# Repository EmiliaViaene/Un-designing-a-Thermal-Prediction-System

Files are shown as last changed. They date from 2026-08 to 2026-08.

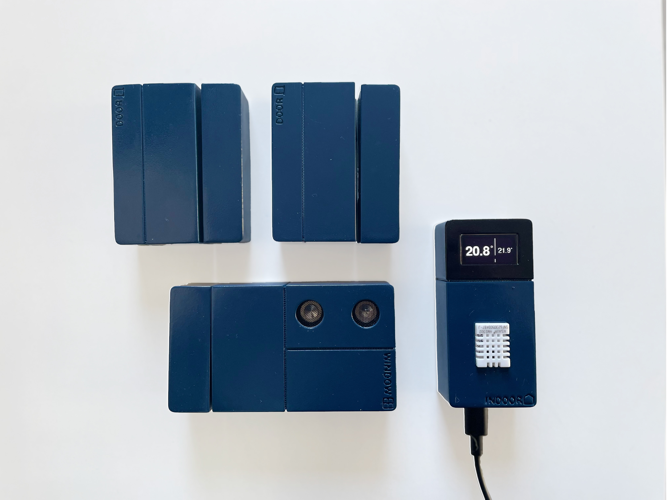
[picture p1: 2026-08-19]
documentation/images/IMG_2418_whiteBG.jpg

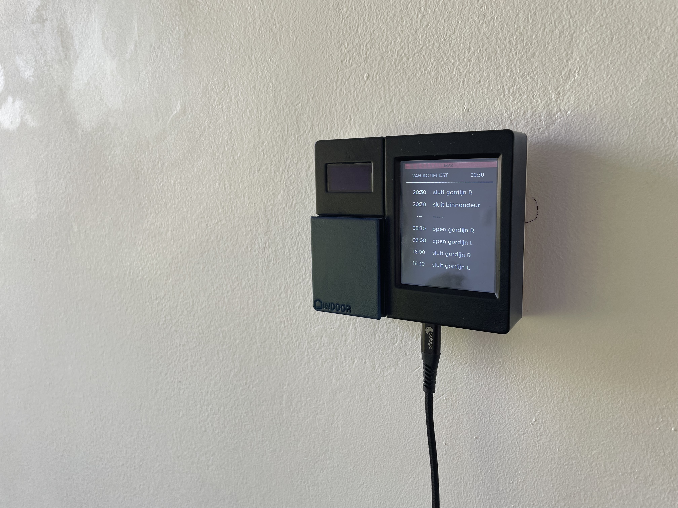
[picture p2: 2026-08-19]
documentation/images/IMG_2538.jpg

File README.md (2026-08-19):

# (Un)designing a Thermal Prediction System
This repository contains the working code, data, 3d-print files, and documentation for a thermal prediction system consisting of four types of sensor devices and an interface. The purpose of this system was to make predictions for changes in the indoor temperature based on weather forecasts and patterns in the thermodynamics of a specific space. These predictions served to anticipate the thermal effects of various shading and ventilating actions. This project is part of a Research through Design study presented in Chapter 6 of the PhD thesis titled: "(Un)designing Learning Agents in Messy Domestic Contexts" by Emilia Viaene (Eindhoven University of Technology, 2026).

# About the Study
This repository accompanies a Research-through-Design  study that explored the role a thermal prediction system (based on thermodynamic sensor data and weather data) could play in supporting household shading and ventilating strategies for thermal comfort. 

The study addressed two research questions:
1. What aspects of household shading and ventilating strategies can or cannot be modeled and predicted by a thermal prediction system based on sensor and weather data?
2. In what ways can suggestions for shading and ventilating actions based on thermal predictions inferred from sensor and weather data be misaligned with situated circumstances?

Four households (H1–H4 in this repository, matching Table 6.1 in the thesis; H4 is the researcher's own household) had a custom sensor kit installed in their living space for several weeks in August–October 2024. The sensor kit logged indoor/outdoor temperature, incoming sunlight through the windows, and window/curtain/door states, supplemented with weather API data. This data was used to iteratively design and deploy a thermal prediction algorithm and an interface that visualized sensor data and, in a later version, simulated thermal effects and suggested shading/ventilating actions.

# Sensor Kit
The sensor kit was designed and developed specifically for the purpose of this study. The complete kit consisted of four sensor devices (described below), equipped with an ESP32-microcontroller. The sensor devices collected thermodynamic variables (temperatures and sunlight) and shading and ventilation states (windows, curtains, doors, and shading). Sensor data was supplemented with API data from local weather stations (outdoor temperature and solar radiation). Data was collected using [DataFoundry](https://data-foundry.net), a research data infrastructure for designers; weather data was collected via the APIs from [OpenWeatherMap](https://openweathermap.org/) and [Meteoserver](https://meteoserver.nl/).

### Windows
The window sensor devices combined an ultrasonic distance sensor to track when curtains were open or closed with an LDR sensor to register changes in incoming light through the window. These devices were installed on each window in the space and logged sensor states at a frequency of sixty seconds When windows stretched over an entire façade, window sensor devices were installed at opposite sides of the window. The purpose of these sensor devices was to capture data about when and how the room was shaded from the sun. Light sensor data was complemented with global solar radiance API data to account for local obstructions in front of the sensor that obstruct the sunlight from hitting a specific (area of a) window.

### Doors
The door sensor devices, equipped with reed sensors to detect when windows or doors were opened or closed. These sensors were installed on windows and outdoor and indoor doors that lead into the space. They logged the reed sensor state with a frequency of sixty seconds. These devices provided data about when the room was exposed to airflow from outside.

### Indoor Temperature
The indoor temperature device included a DHT22 temperature sensor (±0.5°C accuracy) and logged indoor temperature at a frequency of sixty seconds. A small SSD1306 OLED display showed the current indoor and outdoor temperature. While the DHT22 sensor is also capable of collecting humidity data, and while this data is also relevant for the air quality and sensed temperature on the skin, this data was not used in the current study. The indoor temperature data served to provide insight into temperature changes as a result from shading and ventilating actions (i.e., changes in window and door sensor states).  

### Outdoor temperature
The outdoor temperature devices were equipped with waterproof DS18B20 temperature sensors (±0.5°C accuracy). These sensors were placed outside the home of the participants in a shaded area and logged outdoor temperature with a frequency of sixty minutes. This outdoor temperature data served to provide insight into the effect on indoor temperatures in relation to window and door sensor states. This sensor data was complemented with API outdoor temperature data to account for peaks in the data due to e.g. direct sunlight on the sensor.

### Weather data from external APIs
Temperature measurements from nearby weather-stations were accessed from an API called OpenWeatherMap. Global solar radiance measurements were accessed from an API called Meteoserver. Both API data streams were logged at hourly intervals. For the purpose of generating thermal predictions, APIs from the same platforms were used to access forecast data about outdoor temperatures and global solar radiance.

# Thermal Prediction Algorithm
The objective for designing the thermal prediction algorithm was to generate thermal predictions for the next 24 hours and corresponding action lists for shading and ventilating. The resulting algorithm would use weather forecast data to predict fluctuations in indoor temperature under different configurations of window, door, curtain, and shading states. The development of this algorithm was explored using Python Notebooks. The final deployment was based on simulated predictions following the algorithmic logic of the final version of the experimental algorithm. 

### Solar Radiance Model
Because obstructions (e.g., overhangs, trees) are window-specific, the algorithm needed to align global solar radiation measurements with the locally measured light values for each window. This was to ensure that thermal predictions based on solar radiance forecasts were in line with future window-specific light values. The feature set used for this model includes solar radiance values and timestamps (day, time) as input variables and window-specific light sensor values as output variable

### Thermal Prediction Model
Next, the resulting window-specific light value predictions based on solar radiance forecasts in combination with outdoor temperature forecast data served to predict indoor temperature fluctuations based on simulated future window and door sensor states. The feature set used for this model includes outdoor temperature, predicted light values (output from previous model), and pre-set window and door sensor values as input variables and indoor temperatures as output variables. 

### Action List Generation
Finally, the algorithm needed to predict the maximum and minimum temperatures for the next 24 hours and a list of corresponding window and door sensor states.  To do so, the thermal prediction model would run through all possible sensor states for each of the next 24 hours to output the sensor states that correspond with either the max or the min setting.

# Interface
The interface used a TFT LCD touchscreen with an included ESP32 development board (ESP32-2432S028R, commonly referred to as Cheap Yellow Display or CYD). The display was programmed using Arduino, and the graphical user interface was designed using SquareLine Studio. Through the interface, household-specific data from the datasets on the DataFoundry database could be retrieved and manipulated. Two iterations of the interface were deployed consecutively. In the first version, participants could consult historical sensor- and weather data visualizations. The second version enabled participants to configure future window and sensor states and consult corresponding thermal predictions and shading and ventilating action lists.

# Data Infrastructure
The sensor devices were equipped with ESP32 microcontrollers with Wi-Fi capabilities that allowed them to send data from the sensors to a secure database on DataFoundry. Data from each sensor device and from the API’s was collected in five separate datasets on the DataFoundry platform. These datasets were accessed for data processing to produce new (dynamic) datasets to be accessed by the interface.
All sensor devices except the indoor temperature device were powered by lithium-ion batteries. To notify users when the batteries were drained and required recharging (with the supplied portable power bank), a script running on the DataFoundry platform detected when sensor data logging had stopped and then sent notifications to participants through a Telegram bot. 
Two Python scripts served to make the collected data and the output of the thermal prediction algorithm accessible from the interface. The first script merged hourly data from the separate datasets for each participant from the last three days and sent it to a dynamic dataset on DataFoundry. This dataset could be accessed by the interface to display the (household-specific) sensor and weather data history. The second script accessed weather forecast API data (temperature and solar radiance) and ran the thermal prediction algorithm to generate thermal predictions and action lists, to produce dynamic thermal prediction datasets per household. These dynamic datasets can be accessed by the interface to display the thermal predictions and action lists and manipulated by changing thermal prediction settings (i.e., determining future window/door sensor states). Note that this second script was run only once to deploy the simulated thermal predictions for H2.

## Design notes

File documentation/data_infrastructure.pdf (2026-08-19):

## 1. Data collection (sensors)

This document explains the technical details for the Cool AI study setup; how data is sent from and to DataFoundry, to Python notebooks and scripts, and to the interface. On page 1 I explain the data collection part of the project, on page 2 the data processing part, and on page 3 you will fi nd the full diagram (data collection + data processing).

Data is collected at the participants’ home by four kinds of sensor devices: (1) window (reed sensor, light sensor, ultrasonic sensor); (2) door (reed sensor); (3) indoor temperature (DHT22), and (4) outdoor temperature (DS18B20).

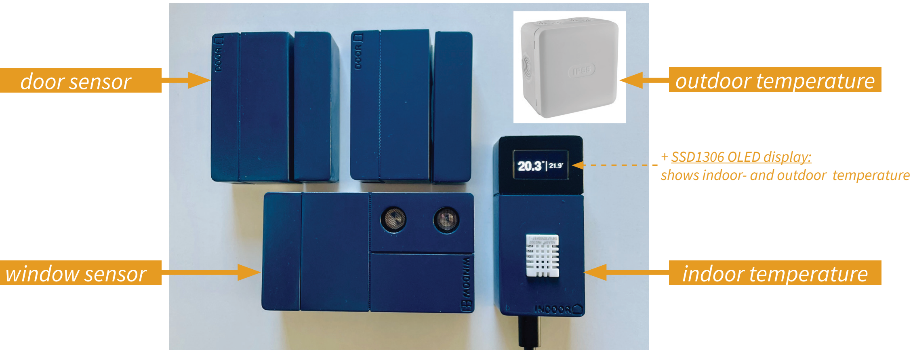
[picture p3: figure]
door sensor; outdoor temperature; window sensor; indoor temperature; + SSD1306 OLED display: shows indoor- and outdoor temperature

These devices are all controlled by an esp32 microcontroller and send data via OOCSI to their resp. IoT databases in DataFoundry. An entity dataset also logs the last timestamps for incoming data from each sensor to monitor whether the battery is still live (& send a Telegram message to the participant to charge the battery in case of dead battery).

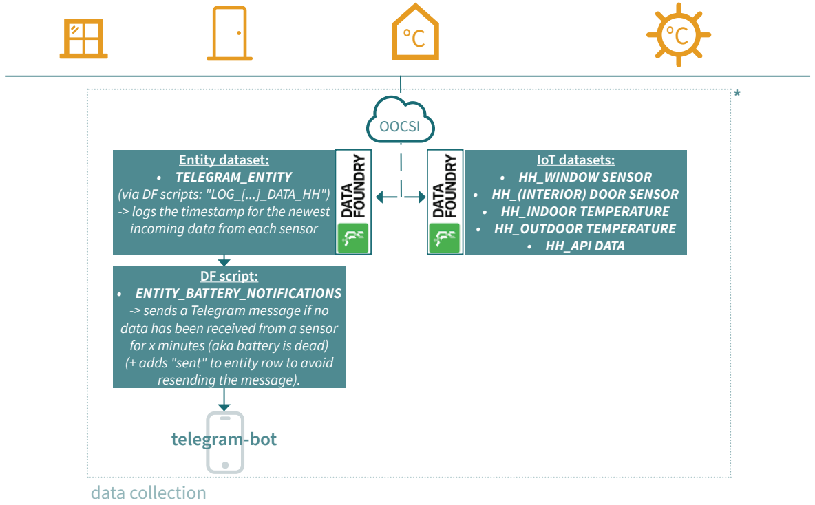
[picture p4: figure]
IoT datasets: • HH_WINDOW SENSOR • HH_(INTERIOR) DOOR SENSOR • HH_INDOOR TEMPERATURE • HH_OUTDOOR TEMPERATURE • HH_API DATA; Entity dataset: • TELEGRAM_ENTITY (via DF scripts: "LOG_[...]_DATA_HH") -> logs the timestamp for the newest incoming data from each sensor; DF script: • ENTITY_BATTERY_NOTIFICATIONS -> sends a Telegram message if no data has been received from a sensor for x minutes (aka battery is dead) (+ adds "sent" to entity row to avoid resending the message).; OOCSI; data collection; telegram-bot

* (The DataFoundry project also contains “PILOT” versions of each dataset and script for testing purposes)

# COOL AI: technical details

## window state door state indoor temperature outdoor temperature

DHT22 sensor (temperature)

DS18B20 sensor (temperature)
OpenWeather api (temperature, description)

reed sensor
ldr sensor
ultrasonic distance sensor reed sensor

## 2. Data processing (to interface)

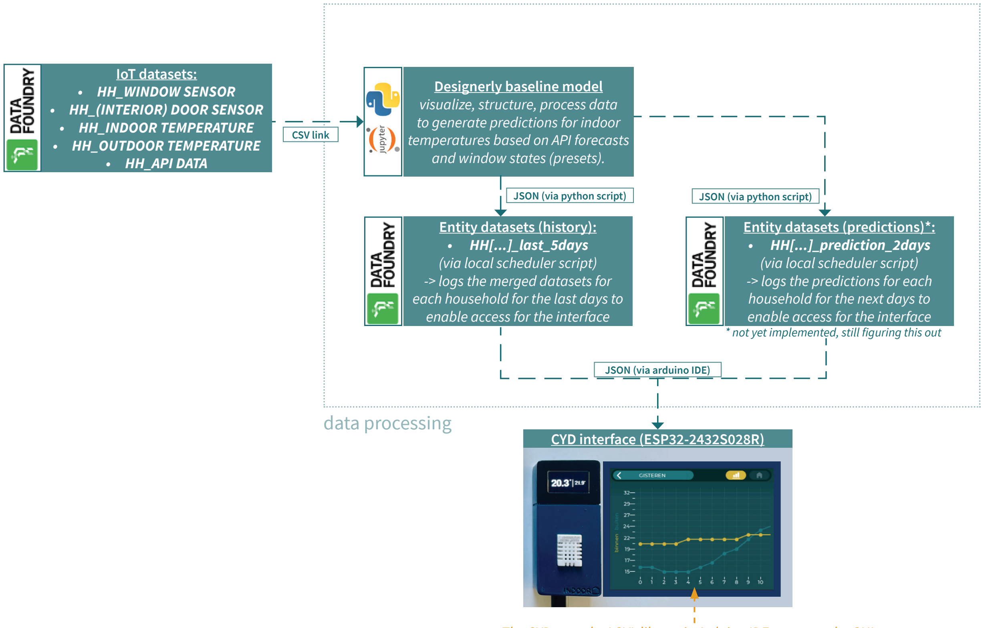
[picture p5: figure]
Designerly baseline model visualize, structure, process data to generate predictions for indoor temperatures based on API forecasts and window states (presets).; Entity datasets (history): • HH[...]_last_5days (via local scheduler script) -> logs the merged datasets for each household for the last days to enable access for the interface; Entity datasets (predictions)*: • HH[...]_prediction_2days (via local scheduler script) -> logs the predictions for each household for the next days to enable access for the interface; CYD interface (ESP32-2432S028R); JSON (via python script); JSON (via arduino IDE); data processing; CSV link; IoT datasets: • HH_WINDOW SENSOR • HH_(INTERIOR) DOOR SENSOR • HH_INDOOR TEMPERATURE • HH_OUTDOOR TEMPERATURE • HH_API DATA

* not yet implemented, still figuring this out

Data from the IoT datasets is accessed via their CSV links in Python Notebooks to visualize, structure, and process the data to create a ‘Designerly Baseline Model’ that generates predictions for indoor temperatures based on forecast (API) data and (preset) window states.

The output from the resulting Python scripts is sent back into (Entity) datasets in DataFoundry, so that the data can be accessed as a JSON by the CYD interface (ESP32-2432S028R). The Python scripts are run at fixed time intervals by a scheduler (local).

The interface has two tabs: “history” and “predictions”:
1. History tab: A python script merges the datasets and sends the last 5 days of relevant data back to an Entity dataset in DataFoundry for each participant. This entity dataset can then be accessed (as a JSON) by the CYD to display this data in the history tab.
2. Predictions tab*: A python script processes the datasets and generates indoor temperature predictions for each window/ curtain/shading state based on API forecast data. This results in multiple datasets (per window/curtain/shading state). These datasets are sent back to (Entity) datasets in DataFoundry so they can be accessed (as JSON) by the CYD to display the predictions and change them according to user input (changing the window/curtain/shading states).
* This part has not been implemented yet, and I am still figuring out how exactly to do this (unsure if this approach will be the final approach).

The CYD uses the LGVL library in Arduino IDE to create the GUI. (+ I use SquareLine to design the GUI)

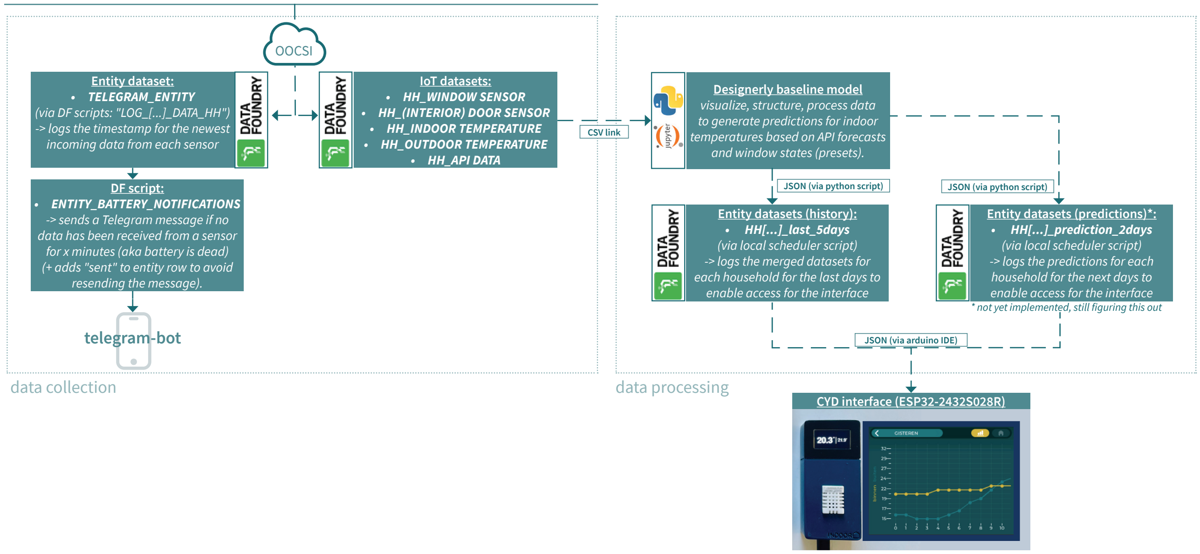
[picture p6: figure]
IoT datasets: • HH_WINDOW SENSOR • HH_(INTERIOR) DOOR SENSOR • HH_INDOOR TEMPERATURE • HH_OUTDOOR TEMPERATURE • HH_API DATA; Designerly baseline model visualize, structure, process data to generate predictions for indoor temperatures based on API forecasts and window states (presets).; Entity dataset: • TELEGRAM_ENTITY (via DF scripts: "LOG_[...]_DATA_HH") -> logs the timestamp for the newest incoming data from each sensor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

* not yet implemented, still fi guring this out

## 3. Full diagram

window state door state | indoor temperature | outdoor temperature
| °C | °C

DHT22 sensor (temperature)

DS18B20 sensor (temperature) OpenWeather api (temperature, description)

reed sensor
ldr sensor
ultrasonic distance sensor reed sensor

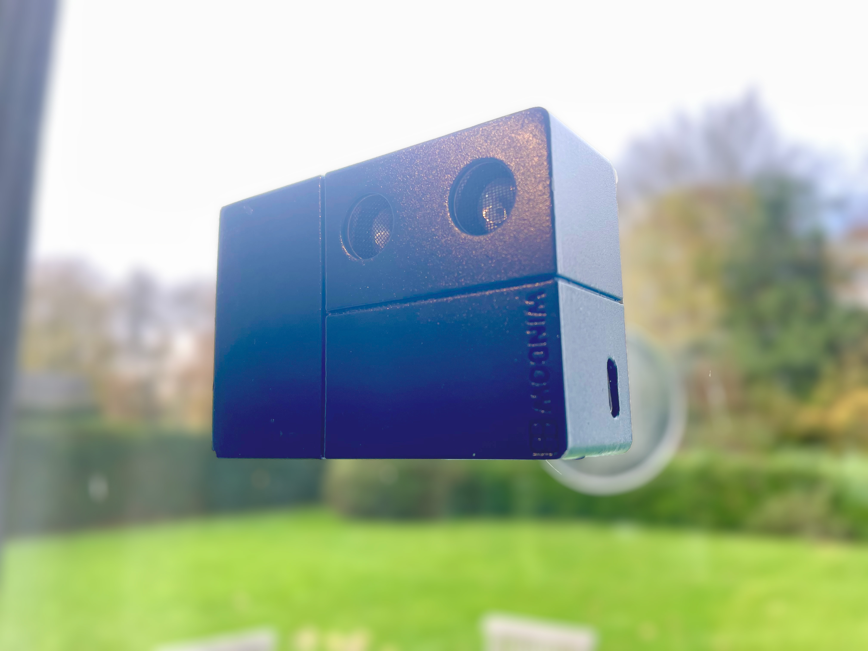
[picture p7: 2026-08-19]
documentation/images/IMG_3446_brighter_blur.jpg

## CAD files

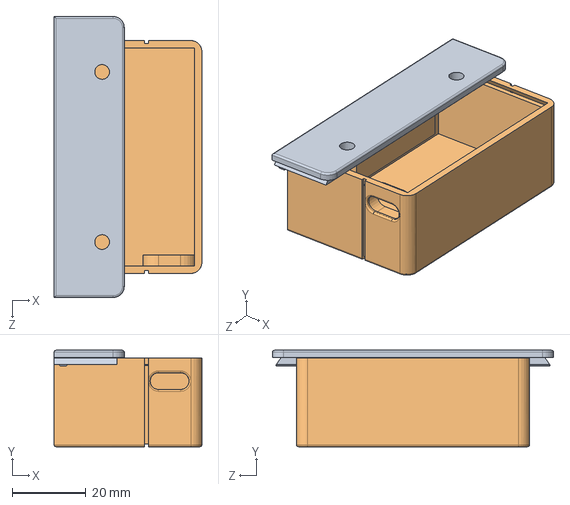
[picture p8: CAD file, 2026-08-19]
hardware/3D_print_files/door-sensor/reed (magnet) box/MAGNET__DOORbox.SLDASM
40.0 x 26.1 x 76.0 mm
MAGNET_DOORbox_V2
MAGNET_DOOR_lid_V2

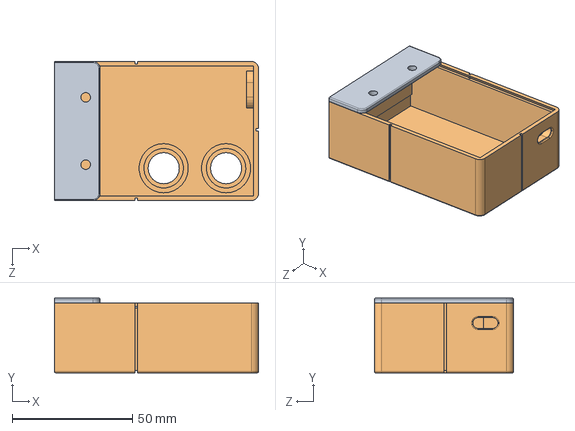
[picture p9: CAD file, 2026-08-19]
hardware/3D_print_files/window-sensor/reed (magnet) box/MAGNET_windowbox.SLDASM
85.0 x 31.1 x 58.0 mm
MAGNET_windowbox_V2
MAGNET_sliding-lid_V2

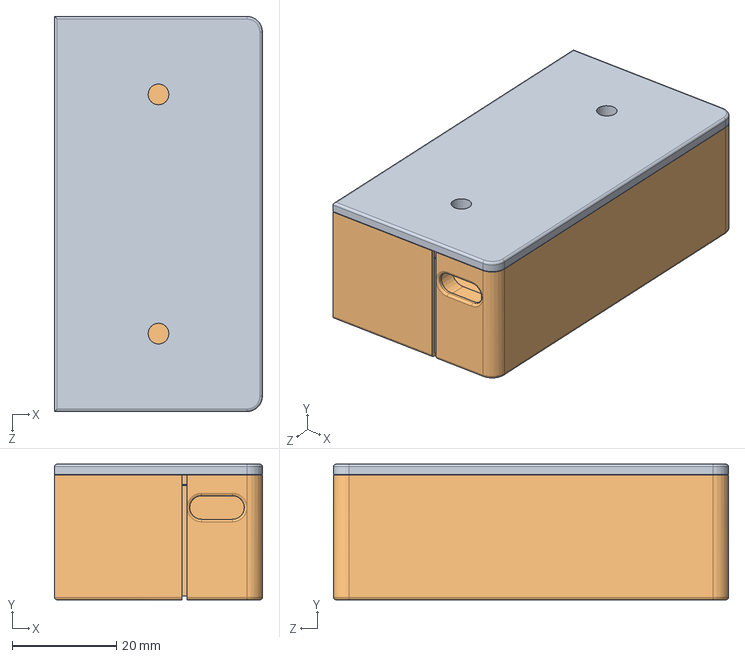
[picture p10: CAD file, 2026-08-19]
hardware/3D_print_files/door-sensor/DOORbox.SLDASM
40.0 x 26.1 x 76.0 mm
DOORwindowbox_V2
DOOR_lid_V2

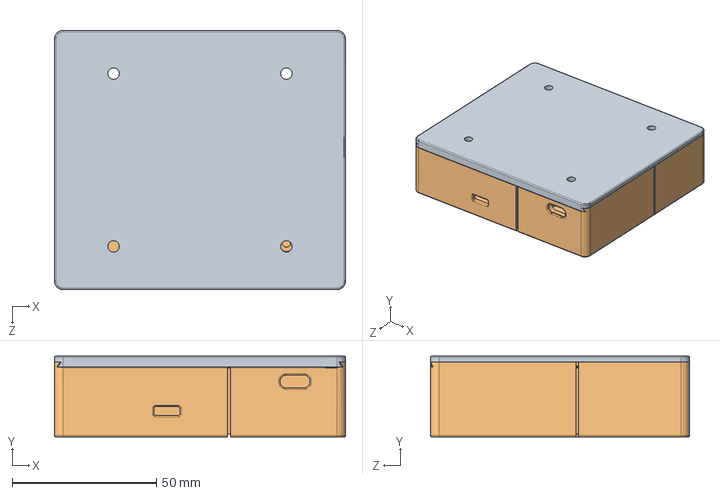
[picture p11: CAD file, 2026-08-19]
hardware/3D_print_files/CYD interface/CYD_combined.SLDASM
101.0 x 28.1 x 90.0 mm
CYD_combined_box
CYD_combined_lid

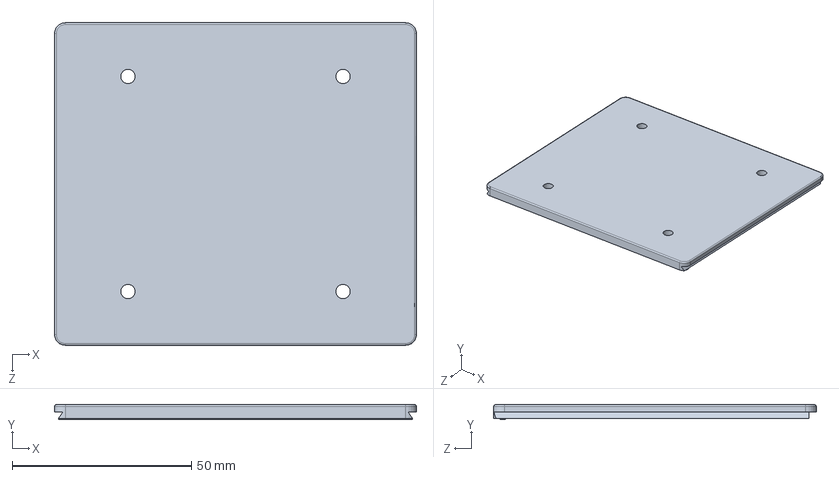
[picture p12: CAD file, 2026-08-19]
hardware/3D_print_files/CYD interface/CYD_combined_lid.SLDPRT
101.0 x 4.10 x 90.0 mm

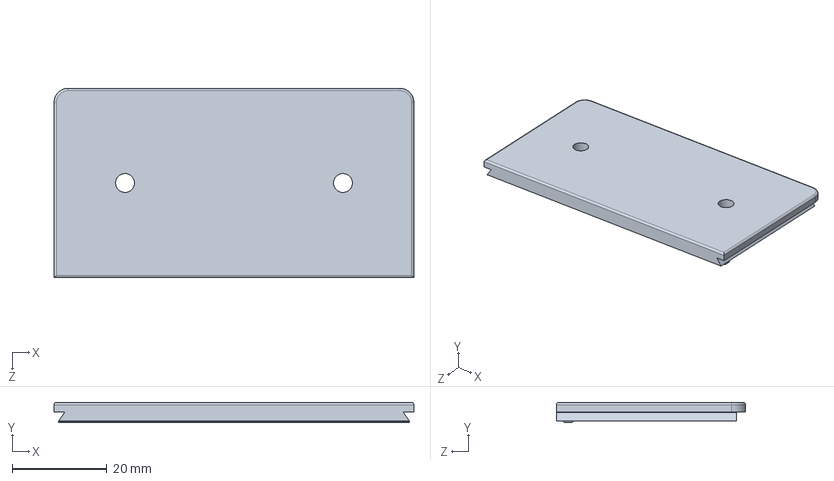
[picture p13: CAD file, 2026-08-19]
hardware/3D_print_files/door-sensor/DOOR_lid_V2.SLDPRT
76.0 x 4.25 x 40.0 mm

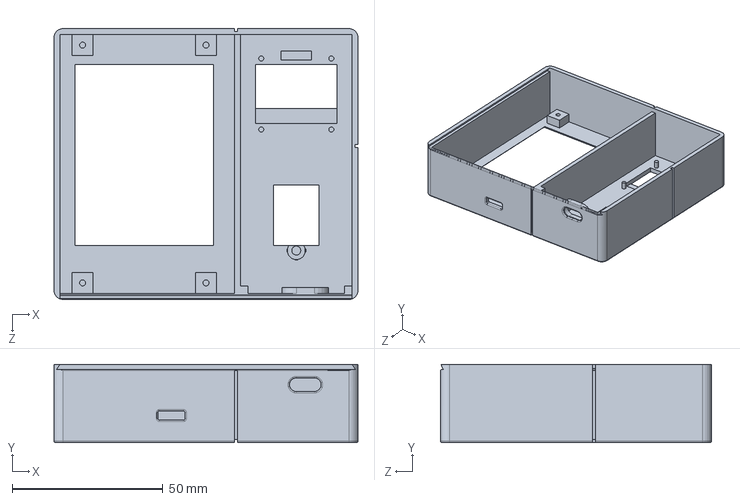
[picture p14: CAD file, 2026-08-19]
hardware/3D_print_files/CYD interface/CYD_combined_box.SLDPRT
101.0 x 26.0 x 90.0 mm

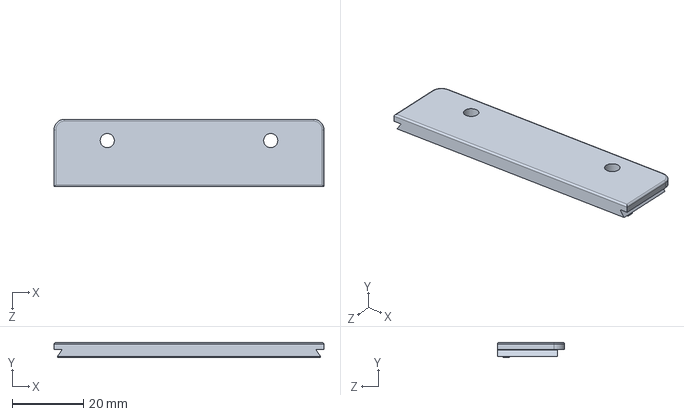
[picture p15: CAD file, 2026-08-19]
hardware/3D_print_files/door-sensor/reed (magnet) box/MAGNET_DOOR_lid_V2.SLDPRT
76.0 x 4.25 x 19.0 mm

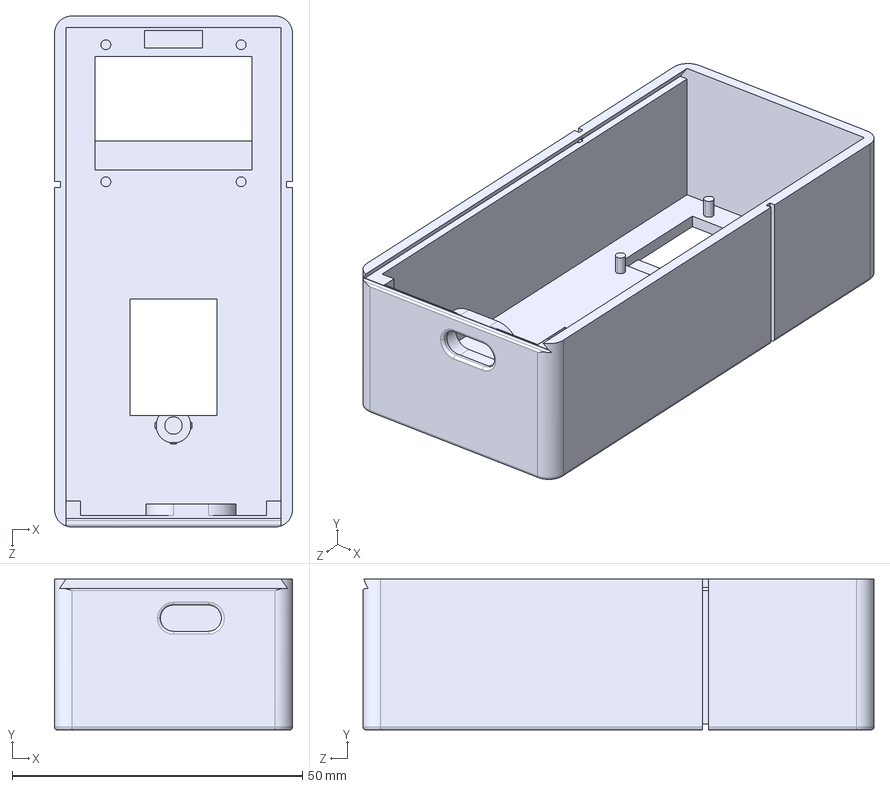
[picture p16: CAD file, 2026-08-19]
hardware/3D_print_files/Indoor/Indoor_box.STEP
41.0 x 26.0 x 88.0 mm

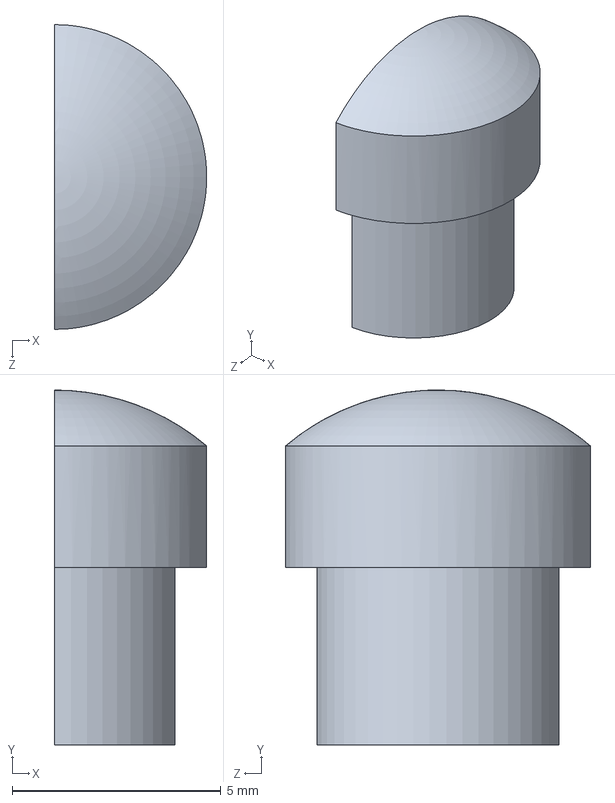
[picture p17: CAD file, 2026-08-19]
hardware/3D_print_files/window-sensor/light sensor dome.SLDPRT
3.65 x 8.50 x 7.30 mm

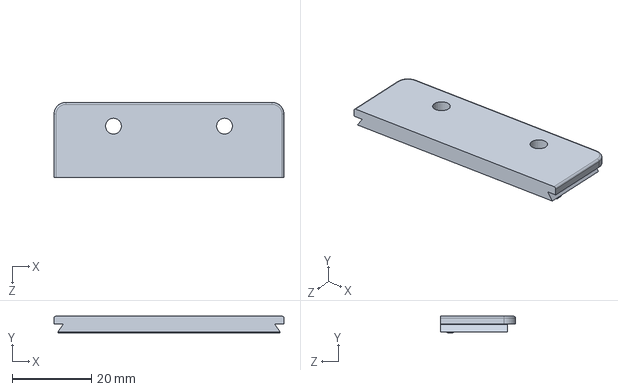
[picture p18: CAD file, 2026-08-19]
hardware/3D_print_files/window-sensor/reed (magnet) box/MAGNET_sliding-lid_V2.SLDPRT
58.0 x 4.20 x 19.0 mm

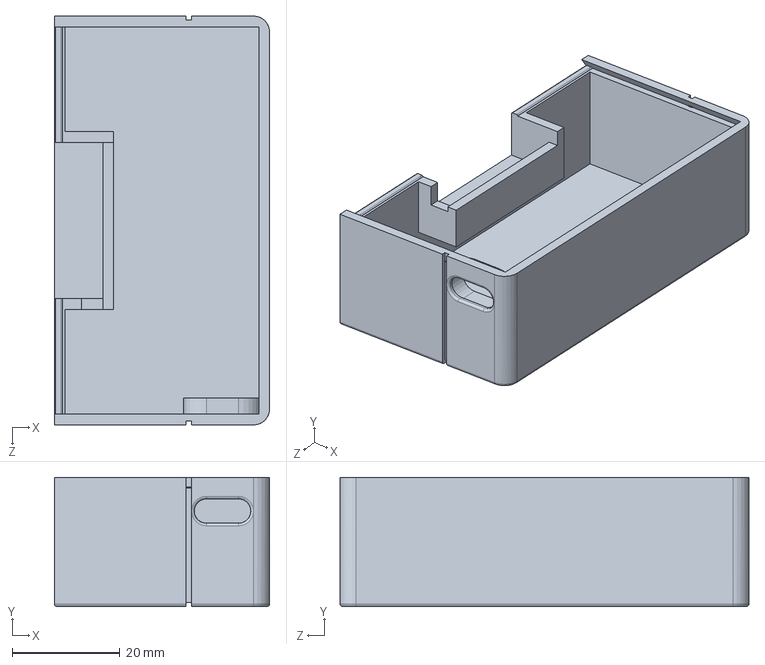
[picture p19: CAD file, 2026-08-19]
hardware/3D_print_files/door-sensor/DOORwindowbox_V2.SLDPRT
40.0 x 24.0 x 76.0 mm

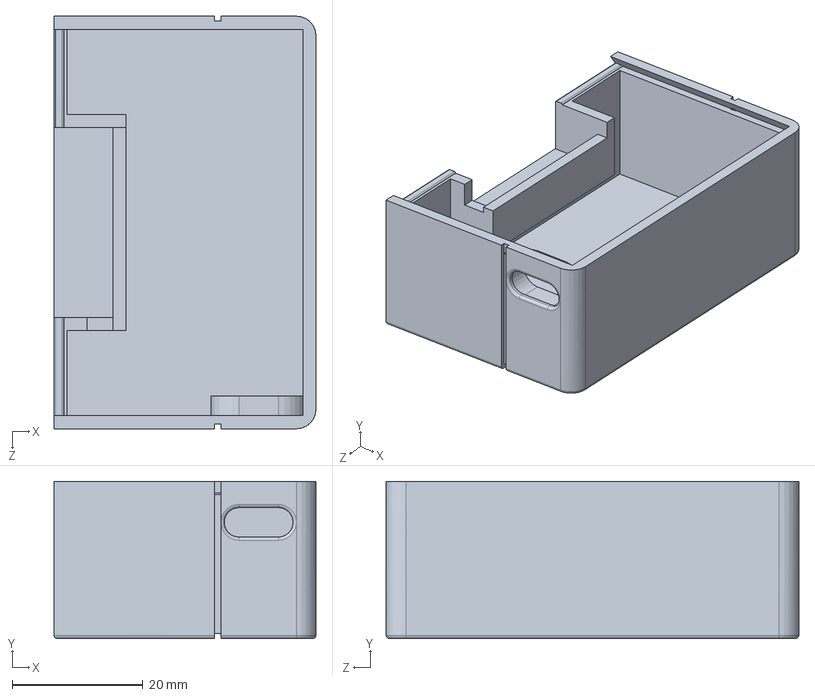
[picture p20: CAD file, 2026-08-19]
hardware/3D_print_files/door-sensor/reed (magnet) box/MAGNET_DOORbox_V2.SLDPRT
40.0 x 24.0 x 63.0 mm

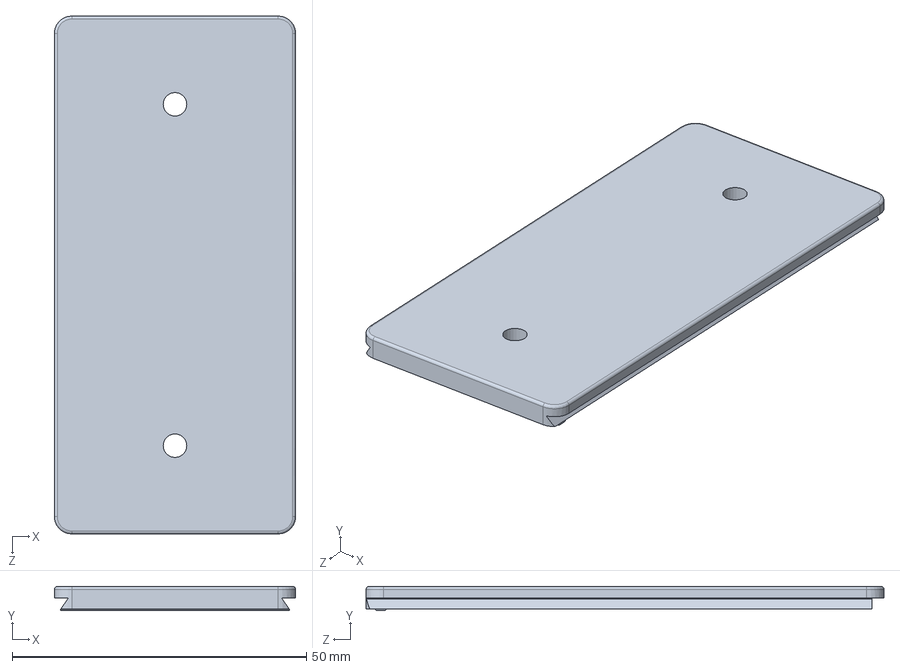
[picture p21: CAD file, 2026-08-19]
hardware/3D_print_files/Indoor/Indoor_lid.SLDPRT
41.0 x 4.10 x 88.0 mm

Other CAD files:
hardware/3D_print_files/Indoor/Indoor.SLDASM
hardware/3D_print_files/window-sensor/windowbox.SLDASM
hardware/3D_print_files/CYD interface/CYD_combined_dekplaatje.SLDPRT
hardware/3D_print_files/window-sensor/reed (magnet) box/MAGNET_windowbox_V2.SLDPRT
hardware/3D_print_files/CYD interface/CYD_combined_box.STL
hardware/3D_print_files/CYD interface/CYD_combined_dekplaatje.STL
hardware/3D_print_files/CYD interface/CYD_combined_lid.STL
hardware/3D_print_files/CYD interface/cyd_box.SLDPRT
hardware/3D_print_files/Indoor/Indoor_box.SLDPRT
hardware/3D_print_files/Indoor/Indoor_lid.STL
hardware/3D_print_files/door-sensor/DOOR_lid_V2.STL
hardware/3D_print_files/door-sensor/DOORwindowbox_V2.STL
hardware/3D_print_files/door-sensor/reed (magnet) box/MAGNET_DOOR_lid_V2.STL
hardware/3D_print_files/door-sensor/reed (magnet) box/MAGNET_DOORbox_V2.STL
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

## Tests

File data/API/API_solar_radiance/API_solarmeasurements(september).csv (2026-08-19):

straling | ts
0 | 2024-09-01 00:00:00
0 | 2024-09-01 01:00:00
0 | 2024-09-01 02:00:00
0 | 2024-09-01 03:00:00
0 | 2024-09-01 04:00:00
15 | 2024-09-01 05:00:00
55 | 2024-09-01 06:00:00
71 | 2024-09-01 07:00:00
160 | 2024-09-01 08:00:00
217 | 2024-09-01 09:00:00
244 | 2024-09-01 10:00:00
247 | 2024-09-01 11:00:00
223 | 2024-09-01 12:00:00
219 | 2024-09-01 13:00:00
177 | 2024-09-01 14:00:00
122 | 2024-09-01 15:00:00
70 | 2024-09-01 16:00:00
25 | 2024-09-01 17:00:00
1 | 2024-09-01 18:00:00
0 | 2024-09-01 19:00:00
0 | 2024-09-01 20:00:00
0 | 2024-09-01 21:00:00
0 | 2024-09-01 22:00:00
0 | 2024-09-01 23:00:00
0 | 2024-09-02 00:00:00
0 | 2024-09-02 01:00:00
0 | 2024-09-02 02:00:00
0 | 2024-09-02 03:00:00
0 | 2024-09-02 04:00:00
16 | 2024-09-02 05:00:00
59 | 2024-09-02 06:00:00
84 | 2024-09-02 07:00:00
137 | 2024-09-02 08:00:00
209 | 2024-09-02 09:00:00
229 | 2024-09-02 10:00:00
244 | 2024-09-02 11:00:00
238 | 2024-09-02 12:00:00
194 | 2024-09-02 13:00:00
142 | 2024-09-02 14:00:00
103 | 2024-09-02 15:00:00
14 | 2024-09-02 16:00:00
12 | 2024-09-02 17:00:00
1 | 2024-09-02 18:00:00
0 | 2024-09-02 19:00:00
0 | 2024-09-02 20:00:00
0 | 2024-09-02 21:00:00
0 | 2024-09-02 22:00:00
0 | 2024-09-02 23:00:00
0 | 2024-09-03 00:00:00
0 | 2024-09-03 01:00:00
0 | 2024-09-03 02:00:00
0 | 2024-09-03 03:00:00
0 | 2024-09-03 04:00:00
12 | 2024-09-03 05:00:00
51 | 2024-09-03 06:00:00
58 | 2024-09-03 07:00:00
55 | 2024-09-03 08:00:00
77 | 2024-09-03 09:00:00
124 | 2024-09-03 10:00:00
84 | 2024-09-03 11:00:00
92 | 2024-09-03 12:00:00
61 | 2024-09-03 13:00:00
64 | 2024-09-03 14:00:00
63 | 2024-09-03 15:00:00
45 | 2024-09-03 16:00:00
14 | 2024-09-03 17:00:00
0 | 2024-09-03 18:00:00
0 | 2024-09-03 19:00:00
0 | 2024-09-03 20:00:00
0 | 2024-09-03 21:00:00
0 | 2024-09-03 22:00:00
0 | 2024-09-03 23:00:00
0 | 2024-09-04 00:00:00
0 | 2024-09-04 01:00:00
0 | 2024-09-04 02:00:00
0 | 2024-09-04 03:00:00
0 | 2024-09-04 04:00:00
9 | 2024-09-04 05:00:00
28 | 2024-09-04 06:00:00
36 | 2024-09-04 07:00:00
55 | 2024-09-04 08:00:00
77 | 2024-09-04 09:00:00
89 | 2024-09-04 10:00:00
104 | 2024-09-04 11:00:00
126 | 2024-09-04 12:00:00
86 | 2024-09-04 13:00:00
107 | 2024-09-04 14:00:00
14 | 2024-09-04 15:00:00
6 | 2024-09-04 16:00:00
2 | 2024-09-04 17:00:00
0 | 2024-09-04 18:00:00
0 | 2024-09-04 19:00:00
0 | 2024-09-04 20:00:00
0 | 2024-09-04 21:00:00
0 | 2024-09-04 22:00:00
0 | 2024-09-04 23:00:00
0 | 2024-09-05 00:00:00
0 | 2024-09-05 01:00:00
0 | 2024-09-05 02:00:00
0 | 2024-09-05 03:00:00
0 | 2024-09-05 04:00:00
3 | 2024-09-05 05:00:00
10 | 2024-09-05 06:00:00
21 | 2024-09-05 07:00:00
29 | 2024-09-05 08:00:00
30 | 2024-09-05 09:00:00
50 | 2024-09-05 10:00:00
102 | 2024-09-05 11:00:00
173 | 2024-09-05 12:00:00
209 | 2024-09-05 13:00:00
166 | 2024-09-05 14:00:00
118 | 2024-09-05 15:00:00
69 | 2024-09-05 16:00:00
21 | 2024-09-05 17:00:00
0 | 2024-09-05 18:00:00
0 | 2024-09-05 19:00:00
0 | 2024-09-05 20:00:00
0 | 2024-09-05 21:00:00
0 | 2024-09-05 22:00:00
0 | 2024-09-05 23:00:00
0 | 2024-09-06 00:00:00
0 | 2024-09-06 01:00:00
0 | 2024-09-06 02:00:00
0 | 2024-09-06 03:00:00
0 | 2024-09-06 04:00:00
4 | 2024-09-06 05:00:00
15 | 2024-09-06 06:00:00
41 | 2024-09-06 07:00:00
54 | 2024-09-06 08:00:00
53 | 2024-09-06 09:00:00
72 | 2024-09-06 10:00:00
69 | 2024-09-06 11:00:00
35 | 2024-09-06 12:00:00
30 | 2024-09-06 13:00:00
15 | 2024-09-06 14:00:00
28 | 2024-09-06 15:00:00
33 | 2024-09-06 16:00:00
8 | 2024-09-06 17:00:00
0 | 2024-09-06 18:00:00
0 | 2024-09-06 19:00:00
0 | 2024-09-06 20:00:00
0 | 2024-09-06 21:00:00
0 | 2024-09-06 22:00:00
0 | 2024-09-06 23:00:00
0 | 2024-09-07 00:00:00
0 | 2024-09-07 01:00:00
0 | 2024-09-07 02:00:00
0 | 2024-09-07 03:00:00
0 | 2024-09-07 04:00:00
8 | 2024-09-07 05:00:00
25 | 2024-09-07 06:00:00
68 | 2024-09-07 07:00:00
140 | 2024-09-07 08:00:00
212 | 2024-09-07 09:00:00
233 | 2024-09-07 10:00:00
240 | 2024-09-07 11:00:00
235 | 2024-09-07 12:00:00
225 | 2024-09-07 13:00:00
177 | 2024-09-07 14:00:00
80 | 2024-09-07 15:00:00
36 | 2024-09-07 16:00:00
7 | 2024-09-07 17:00:00
0 | 2024-09-07 18:00:00
0 | 2024-09-07 19:00:00
0 | 2024-09-07 20:00:00
0 | 2024-09-07 21:00:00
0 | 2024-09-07 22:00:00
0 | 2024-09-07 23:00:00
0 | 2024-09-08 00:00:00
0 | 2024-09-08 01:00:00
0 | 2024-09-08 02:00:00
0 | 2024-09-08 03:00:00
0 | 2024-09-08 04:00:00
3 | 2024-09-08 05:00:00
59 | 2024-09-08 06:00:00
122 | 2024-09-08 07:00:00
174 | 2024-09-08 08:00:00
221 | 2024-09-08 09:00:00
195 | 2024-09-08 10:00:00
224 | 2024-09-08 11:00:00
159 | 2024-09-08 12:00:00
215 | 2024-09-08 13:00:00
182 | 2024-09-08 14:00:00
81 | 2024-09-08 15:00:00
67 | 2024-09-08 16:00:00
21 | 2024-09-08 17:00:00
0 | 2024-09-08 18:00:00
0 | 2024-09-08 19:00:00
0 | 2024-09-08 20:00:00
0 | 2024-09-08 21:00:00
0 | 2024-09-08 22:00:00
0 | 2024-09-08 23:00:00
0 | 2024-09-09 00:00:00
0 | 2024-09-09 01:00:00
0 | 2024-09-09 02:00:00
0 | 2024-09-09 03:00:00
0 | 2024-09-09 04:00:00
2 | 2024-09-09 05:00:00
19 | 2024-09-09 06:00:00
36 | 2024-09-09 07:00:00
110 | 2024-09-09 08:00:00
94 | 2024-09-09 09:00:00
134 | 2024-09-09 10:00:00
83 | 2024-09-09 11:00:00
189 | 2024-09-09 12:00:00
64 | 2024-09-09 13:00:00
128 | 2024-09-09 14:00:00
154 | 2024-09-09 15:00:00
74 | 2024-09-09 16:00:00
4 | 2024-09-09 17:00:00
0 | 2024-09-09 18:00:00
0 | 2024-09-09 19:00:00
0 | 2024-09-09 20:00:00
0 | 2024-09-09 21:00:00
0 | 2024-09-09 22:00:00
0 | 2024-09-09 23:00:00
0 | 2024-09-10 00:00:00
0 | 2024-09-10 01:00:00
0 | 2024-09-10 02:00:00
0 | 2024-09-10 03:00:00
0 | 2024-09-10 04:00:00
5 | 2024-09-10 05:00:00
45 | 2024-09-10 06:00:00
104 | 2024-09-10 07:00:00
132 | 2024-09-10 08:00:00
154 | 2024-09-10 09:00:00
112 | 2024-09-10 10:00:00
65 | 2024-09-10 11:00:00
84 | 2024-09-10 12:00:00
50 | 2024-09-10 13:00:00
62 | 2024-09-10 14:00:00
21 | 2024-09-10 15:00:00
8 | 2024-09-10 16:00:00
1 | 2024-09-10 17:00:00
0 | 2024-09-10 18:00:00
0 | 2024-09-10 19:00:00
0 | 2024-09-10 20:00:00
0 | 2024-09-10 21:00:00
0 | 2024-09-10 22:00:00
0 | 2024-09-10 23:00:00
0 | 2024-09-11 00:00:00
0 | 2024-09-11 01:00:00
0 | 2024-09-11 02:00:00
0 | 2024-09-11 03:00:00
0 | 2024-09-11 04:00:00
8 | 2024-09-11 05:00:00
62 | 2024-09-11 06:00:00
118 | 2024-09-11 07:00:00
156 | 2024-09-11 08:00:00
90 | 2024-09-11 09:00:00
208 | 2024-09-11 10:00:00
163 | 2024-09-11 11:00:00
140 | 2024-09-11 12:00:00
88 | 2024-09-11 13:00:00
72 | 2024-09-11 14:00:00
29 | 2024-09-11 15:00:00
35 | 2024-09-11 16:00:00
7 | 2024-09-11 17:00:00
0 | 2024-09-11 18:00:00
0 | 2024-09-11 19:00:00
0 | 2024-09-11 20:00:00
0 | 2024-09-11 21:00:00
0 | 2024-09-11 22:00:00
0 | 2024-09-11 23:00:00
0 | 2024-09-12 00:00:00
0 | 2024-09-12 01:00:00
0 | 2024-09-12 02:00:00
0 | 2024-09-12 03:00:00
0 | 2024-09-12 04:00:00
10 | 2024-09-12 05:00:00
51 | 2024-09-12 06:00:00
82 | 2024-09-12 07:00:00
161 | 2024-09-12 08:00:00
194 | 2024-09-12 09:00:00
177 | 2024-09-12 10:00:00
102 | 2024-09-12 11:00:00
147 | 2024-09-12 12:00:00
181 | 2024-09-12 13:00:00
135 | 2024-09-12 14:00:00
125 | 2024-09-12 15:00:00
45 | 2024-09-12 16:00:00
7 | 2024-09-12 17:00:00
0 | 2024-09-12 18:00:00
0 | 2024-09-12 19:00:00
0 | 2024-09-12 20:00:00
0 | 2024-09-12 21:00:00
0 | 2024-09-12 22:00:00
0 | 2024-09-12 23:00:00
0 | 2024-09-13 00:00:00
0 | 2024-09-13 01:00:00
0 | 2024-09-13 02:00:00
0 | 2024-09-13 03:00:00
0 | 2024-09-13 04:00:00
8 | 2024-09-13 05:00:00
57 | 2024-09-13 06:00:00
114 | 2024-09-13 07:00:00
146 | 2024-09-13 08:00:00
146 | 2024-09-13 09:00:00
147 | 2024-09-13 10:00:00
129 | 2024-09-13 11:00:00
79 | 2024-09-13 12:00:00
169 | 2024-09-13 13:00:00
144 | 2024-09-13 14:00:00
104 | 2024-09-13 15:00:00
33 | 2024-09-13 16:00:00
11 | 2024-09-13 17:00:00
0 | 2024-09-13 18:00:00
0 | 2024-09-13 19:00:00
0 | 2024-09-13 20:00:00
0 | 2024-09-13 21:00:00
0 | 2024-09-13 22:00:00
0 | 2024-09-13 23:00:00
0 | 2024-09-14 00:00:00
0 | 2024-09-14 01:00:00
0 | 2024-09-14 02:00:00
0 | 2024-09-14 03:00:00
0 | 2024-09-14 04:00:00
10 | 2024-09-14 05:00:00
50 | 2024-09-14 06:00:00
108 | 2024-09-14 07:00:00
158 | 2024-09-14 08:00:00
184 | 2024-09-14 09:00:00
216 | 2024-09-14 10:00:00
224 | 2024-09-14 11:00:00
158 | 2024-09-14 12:00:00
144 | 2024-09-14 13:00:00
131 | 2024-09-14 14:00:00
78 | 2024-09-14 15:00:00
35 | 2024-09-14 16:00:00
8 | 2024-09-14 17:00:00
0 | 2024-09-14 18:00:00
0 | 2024-09-14 19:00:00
0 | 2024-09-14 20:00:00
0 | 2024-09-14 21:00:00
0 | 2024-09-14 22:00:00
0 | 2024-09-14 23:00:00
0 | 2024-09-15 00:00:00
0 | 2024-09-15 01:00:00
0 | 2024-09-15 02:00:00
0 | 2024-09-15 03:00:00
0 | 2024-09-15 04:00:00
7 | 2024-09-15 05:00:00
42 | 2024-09-15 06:00:00
100 | 2024-09-15 07:00:00
133 | 2024-09-15 08:00:00
165 | 2024-09-15 09:00:00
171 | 2024-09-15 10:00:00
100 | 2024-09-15 11:00:00
179 | 2024-09-15 12:00:00
100 | 2024-09-15 13:00:00
134 | 2024-09-15 14:00:00
52 | 2024-09-15 15:00:00
43 | 2024-09-15 16:00:00
3 | 2024-09-15 17:00:00
0 | 2024-09-15 18:00:00
0 | 2024-09-15 19:00:00
0 | 2024-09-15 20:00:00
0 | 2024-09-15 21:00:00
0 | 2024-09-15 22:00:00
0 | 2024-09-15 23:00:00
0 | 2024-09-16 00:00:00
0 | 2024-09-16 01:00:00
0 | 2024-09-16 02:00:00
0 | 2024-09-16 03:00:00
0 | 2024-09-16 04:00:00
6 | 2024-09-16 05:00:00
29 | 2024-09-16 06:00:00
42 | 2024-09-16 07:00:00
70 | 2024-09-16 08:00:00
78 | 2024-09-16 09:00:00
132 | 2024-09-16 10:00:00
105 | 2024-09-16 11:00:00
124 | 2024-09-16 12:00:00
132 | 2024-09-16 13:00:00
78 | 2024-09-16 14:00:00
95 | 2024-09-16 15:00:00
25 | 2024-09-16 16:00:00
3 | 2024-09-16 17:00:00
0 | 2024-09-16 18:00:00
0 | 2024-09-16 19:00:00
0 | 2024-09-16 20:00:00
0 | 2024-09-16 21:00:00
0 | 2024-09-16 22:00:00
0 | 2024-09-16 23:00:00
0 | 2024-09-17 00:00:00
0 | 2024-09-17 01:00:00
0 | 2024-09-17 02:00:00
0 | 2024-09-17 03:00:00
0 | 2024-09-17 04:00:00
3 | 2024-09-17 05:00:00
39 | 2024-09-17 06:00:00
102 | 2024-09-17 07:00:00
150 | 2024-09-17 08:00:00
189 | 2024-09-17 09:00:00
217 | 2024-09-17 10:00:00
237 | 2024-09-17 11:00:00
220 | 2024-09-17 12:00:00
193 | 2024-09-17 13:00:00
153 | 2024-09-17 14:00:00
103 | 2024-09-17 15:00:00
48 | 2024-09-17 16:00:00
6 | 2024-09-17 17:00:00
0 | 2024-09-17 18:00:00
0 | 2024-09-17 19:00:00
0 | 2024-09-17 20:00:00
0 | 2024-09-17 21:00:00
0 | 2024-09-17 22:00:00
0 | 2024-09-17 23:00:00
0 | 2024-09-18 00:00:00
0 | 2024-09-18 01:00:00
0 | 2024-09-18 02:00:00
0 | 2024-09-18 03:00:00
0 | 2024-09-18 04:00:00
2 | 2024-09-18 05:00:00
11 | 2024-09-18 06:00:00
23 | 2024-09-18 07:00:00
33 | 2024-09-18 08:00:00
69 | 2024-09-18 09:00:00
155 | 2024-09-18 10:00:00
189 | 2024-09-18 11:00:00
206 | 2024-09-18 12:00:00
174 | 2024-09-18 13:00:00
140 | 2024-09-18 14:00:00
97 | 2024-09-18 15:00:00
45 | 2024-09-18 16:00:00
6 | 2024-09-18 17:00:00
0 | 2024-09-18 18:00:00
0 | 2024-09-18 19:00:00
0 | 2024-09-18 20:00:00
0 | 2024-09-18 21:00:00
0 | 2024-09-18 22:00:00
0 | 2024-09-18 23:00:00
0 | 2024-09-19 00:00:00
0 | 2024-09-19 01:00:00
0 | 2024-09-19 02:00:00
0 | 2024-09-19 03:00:00
0 | 2024-09-19 04:00:00
4 | 2024-09-19 05:00:00
37 | 2024-09-19 06:00:00
88 | 2024-09-19 07:00:00
141 | 2024-09-19 08:00:00
182 | 2024-09-19 09:00:00
211 | 2024-09-19 10:00:00
221 | 2024-09-19 11:00:00
212 | 2024-09-19 12:00:00
186 | 2024-09-19 13:00:00
143 | 2024-09-19 14:00:00
94 | 2024-09-19 15:00:00
39 | 2024-09-19 16:00:00
4 | 2024-09-19 17:00:00
0 | 2024-09-19 18:00:00
0 | 2024-09-19 19:00:00
0 | 2024-09-19 20:00:00
0 | 2024-09-19 21:00:00
0 | 2024-09-19 22:00:00
0 | 2024-09-19 23:00:00
0 | 2024-09-20 00:00:00
0 | 2024-09-20 01:00:00
0 | 2024-09-20 02:00:00
0 | 2024-09-20 03:00:00
0 | 2024-09-20 04:00:00
4 | 2024-09-20 05:00:00
38 | 2024-09-20 06:00:00
91 | 2024-09-20 07:00:00
142 | 2024-09-20 08:00:00
182 | 2024-09-20 09:00:00
209 | 2024-09-20 10:00:00
220 | 2024-09-20 11:00:00
213 | 2024-09-20 12:00:00
186 | 2024-09-20 13:00:00
142 | 2024-09-20 14:00:00
93 | 2024-09-20 15:00:00
42 | 2024-09-20 16:00:00
5 | 2024-09-20 17:00:00
0 | 2024-09-20 18:00:00
0 | 2024-09-20 19:00:00
0 | 2024-09-20 20:00:00
0 | 2024-09-20 21:00:00
0 | 2024-09-20 22:00:00
0 | 2024-09-20 23:00:00
0 | 2024-09-21 00:00:00
0 | 2024-09-21 01:00:00
0 | 2024-09-21 02:00:00
0 | 2024-09-21 03:00:00
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

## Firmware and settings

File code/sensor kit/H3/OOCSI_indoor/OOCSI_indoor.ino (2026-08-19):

#include "OOCSI.h"
#include <Wire.h>
#include <Adafruit_GFX.h>
#include <Adafruit_SSD1306.h>
#include "DHT.h"
#include <OneWire.h>
#include <WiFi.h>
#include <HTTPClient.h>
#include <Arduino_JSON.h>
#include <Fonts/FreeSans12pt7b.h>
#include <Fonts/FreeSansBold18pt7b.h>
#include <Fonts/FreeSansBold24pt7b.h>
#include <Fonts/FreeSansBoldOblique24pt7b.h>
#include <Fonts/FreeSans9pt7b.h>
#include <Fonts/FreeSans12pt7b.h>
#include <Fonts/FreeSansBold12pt7b.h>

#define SCREEN_WIDTH 128 // OLED display width, in pixels
#define SCREEN_HEIGHT 64 // OLED display height, in pixels

// Declaration for an SSD1306 display connected to I2C (SDA, SCL pins)
Adafruit_SSD1306 display(SCREEN_WIDTH, SCREEN_HEIGHT, &Wire, -1);

////////////////////////////////////////////////////////////////////////// DHT22
#define DHTPIN 4
#define DHTTYPE DHT22
DHT dht(DHTPIN, DHTTYPE);

// //////////////////////////////////////////////////////////////////////// API
// const char* ssid = "Proximus-Home-92F0";
// // Password of your Wifi network.
// const char* password = "w9bdkm3hjhm6p";

const char* ssid = "Telenet0515971_Guest";
// Password of your Wifi network.
const char* password = "&YZAFWl3$i33";

// Your Domain name with URL path or IP address with path
String openWeatherMapApiKey = "273a7bdc5f26d184400ce98d1bc8e957";
// lat en lon voor: H3
String lat = "51.398220";
String lon = "4.792850";
// For a final application, check the API call limits per hour/minute to avoid getting blocked/banned
unsigned long lastTime = 0;
// Timer set to 1 minutes (60000)
unsigned long timerDelay = 10000;
String jsonBuffer;
String httpGETRequest(const char* serverName) {
  WiFiClient client;
  HTTPClient http;
  // Your Domain name with URL path or IP address with path
  http.begin(client, serverName);
  // Send HTTP POST request
  int httpResponseCode = http.GET();
  String payload = "{}"; 
  if (httpResponseCode>0) {
    Serial.print("HTTP Response code: ");
    Serial.println(httpResponseCode);
    payload = http.getString();
  }
  else {
    Serial.print("Error code: ");
    Serial.println(httpResponseCode);
  }
  // Free resources
  http.end();
  return payload;
}

//////////////////////////////////////////////////////////////////////// SET UP OOCSI
// name for connecting with OOCSI (unique handle)
const char* OOCSIName = "HH3_indoor_data";
// put the adress of your OOCSI server here, can be URL or IP address string
const char* hostserver = "oocsi.id.tue.nl";
// OOCSI reference for the entire sketch
OOCSI oocsi = OOCSI();


//////////////////////////////////////////////////////////////////////// OOCSI RECEIVE OUTDOOR TEMP DATA
float Temperature_sensor; // declare the float and rounded int to call the sensorvalues
int Temperature_sensor_round;
// function which OOCSI calls when an OOCSI message is received
void processOOCSI() {
  float Temperature_HH3 = oocsi.getFloat("Temperature", -200.0);
  String Participant_HH3 = oocsi.getString("participant", "");

  if (Temperature_HH3 > -30.0 && Participant_HH3 == "H3") { // only return the temperature if its value is not rogue & specify which household I want the data from
    Temperature_sensor = oocsi.getFloat("Temperature", -200.0);
    Temperature_sensor_round = round(Temperature_sensor);
  } 
}


void setup() {
  Serial.begin(9600);
  ////////////////////////////////////////////////////////////////////////// check bme280 sensor & start wifi
  dht.begin();
  WiFi.begin(ssid, password);

  ////////////////////////////////////////////////////////////////////////// setting up OOCSI
  // setting up OOCSI. processOOCSI is the name of the function to call when receiving messages, can be a random function name
  oocsi.connect(OOCSIName, hostserver, ssid, password, processOOCSI);
  // subscribe to a channel (for receiving messages)
  oocsi.subscribe("HH_outdoor_temp");

  ////////////////////////////////////////////////////////////////////////// setting up the OLED display
  if(!display.begin(SSD1306_SWITCHCAPVCC, 0x3C)) { // Address 0x3D for 128x64
    Serial.println(F("SSD1306 allocation failed"));
    for(;;);
  }
  delay(2000);
  display.clearDisplay();
  display.setTextColor(WHITE);
}


void loop() { 

  display.clearDisplay(); //clear the display so values are not printed on top of each other

  ////////////////////////////////////////////////////////////////////////// GET, DISPLAY, AND SEND TEMPERATURE SENSOR DATA
  float temperature = dht.readTemperature();
  float temperature_corrected = temperature - 2.7;
  int temperature_round = round(temperature);

  // send the value to the OLED
  display.setFont(&FreeSansBold18pt7b);
  display.setCursor(0, 45);
  // Display static text
  display.println(temperature_corrected, 1);

  // Send the value to OOCSI (Datafoundry dataset)
  oocsi.newMessage("HH_INDOOR_receiver");
  // replace DEVICE with your reference ID from a device
  oocsi.addString("device_id", "d1583e8bf757149f0");
  // identify participant
  oocsi.addString("participant", "H3");

  // add outdoor temperature data to be stored in the dataset
  oocsi.addFloat("Temperature", temperature_corrected);

  oocsi.sendMessage();   // this command will send the message; don't forget to call this after creating a message
  oocsi.printSendMessage();   // prints out the raw message (how it is sent to the OOCSI server)


  ////////////////////////////////////////////////////////////////////////// GET API DATA
  String serverPath = "http://api.openweathermap.org/data/2.5/weather?lat=" + lat + "&lon=" + lon + "&appid=" + openWeatherMapApiKey + "&units=metric";
  jsonBuffer = httpGETRequest(serverPath.c_str());
  Serial.println(jsonBuffer);
  JSONVar myObject = JSON.parse(jsonBuffer);
  // ARDUINOJSON_USE_DOUBLE;
  // JSON.typeof(jsonVar) can be used to get the type of the var
  if (JSON.typeof(myObject) == "undefined") {
    Serial.println("Parsing input failed!");
    return;
  }

  // make OOCSI message ready. Insert DF channel here
  oocsi.newMessage("HH_API_data");
  // replace DEVICE with your reference ID from a device
  oocsi.addString("device_id", "db13a3330148d420a");
  // identify participant
  oocsi.addString("participant", "H3");

  oocsi.addFloat("Temperature_API", (double) myObject["main"]["temp"]);
  oocsi.addFloat("Temperature_API_MIN", (double) myObject["main"]["temp_min"]);
  oocsi.addFloat("Temperature_API_MAX", (double) myObject["main"]["temp_max"]);
  oocsi.addString("weather_main", myObject["weather"][0]["main"]);
  oocsi.addString("weather_description", myObject["weather"][0]["description"]);

  oocsi.sendMessage();   // this command will send the message; don't forget to call this after creating a message
  oocsi.printSendMessage();   // prints out the raw message (how it is sent to the OOCSI server)
  oocsi.check();   // use the check() if you also need to process incoming messages/ use keepAlive() if you do NOT need to receive data from OOCSI

  // get a mean api temperature value to display on the OLED
  float API_temperature = (double) myObject["main"]["temp"];
  int API_temperature_round = round(API_temperature);


  ////////////////////////////////////////////////////////////////////////// RECEIVE OOCSI OUTDOOR TEMP DATA & CALCULATE MEAN OUTDOOR TEMP (WITH API VALUE)
  processOOCSI(); // get the oocsi sensor values from the function declared above
  int Temperature_mean = (API_temperature_round + Temperature_sensor_round)/2; // calculate the mean of the api and oocsi value


  //////////////////////////////////////////////////////////////////////////  CALCULATE & DISPLAY MEAN OUTDOOR TEMP (WITH API VALUE)
  Serial.print("Temperature_API: ");
  Serial.println(API_temperature_round);
  Serial.print("Temperature_OOCSI: ");
  Serial.println(Temperature_sensor_round);
  Serial.print("Temperature_mean: ");
  Serial.println(Temperature_mean);

  // DISPLAY THE MEAN TEMP VALUE ON THE OLED
  display.setFont(&FreeSans9pt7b);
  display.setCursor(88, 38);
  // Display static text
  if   (Temperature_sensor > 0 | Temperature_sensor < 0) {
    display.println(Temperature_mean, 1);
  }
  else {
    display.println(API_temperature, 1);
  }


  ////////////////////////////////////////////////////////////////////////// FIXED DISPLAY ELEMENTS
  display.drawCircle(71, 22, 2, WHITE);
  // display.setFont(&FreeSans9pt7b);
  // display.setCursor(60, 48);
  // display.println("in");
  display.drawLine(80, 0, 80, 64, WHITE);
  display.drawCircle(125, 27.5, 1, WHITE);

  display.display();
  delay(60000);  // wait 60 seconds before looping again
}

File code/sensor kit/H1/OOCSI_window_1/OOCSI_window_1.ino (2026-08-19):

#include <OOCSI.h>
#include <Wire.h>
#include <Adafruit_Sensor.h>
#include <Adafruit_BME280.h>

//////////////////////////////////////////////////////////////  FOR OOCSI CONNECTION: 
// use this if you want the OOCSI-ESP library to manage the connection to the Wifi
// SSID of your Wifi network, the library currently does not support WPA2 Enterprise networks
const char* ssid = "VFNL-DF7B08";
// Password of your Wifi network.
const char* password = "4W8DNSU424SP4";
// name for connecting with OOCSI (unique handle)
const char* OOCSIName = "HH1_window_1";
// put the adress of your OOCSI server here, can be URL or IP address string
const char* hostserver = "oocsi.id.tue.nl";
// OOCSI reference for the entire sketch
// To connect to an OOCSI network, that is, a running OOCSI server, you first need to create an OOCSI reference:
OOCSI oocsi = OOCSI();

////////////////////////////////////////////////////////////// assign sensor pins
#define LIGHT_SENSOR_PIN 36 // ESP32 pin GIOP36 connected to LDR sensor's pin
const int trigPin = 5; // trigger pin distance sensor to GPIOP 5 
const int echoPin = 18; // echo pin distance sensor to GPIOP 18

int LDRvalue; //instance for the light sensor (LDR sensor)
#define SOUND_SPEED 0.034 //define sound speed in cm
long duration; // call duration
float distanceCm; // call distance in cm

#define DOOR_SENSOR_PIN  19  // ESP32 pin GPIO19 connected to door sensor's pin
int doorState;

////////////////////////////////////////////////////////////// SLEEP TIMER
const uint32_t SLEEP_DURATION = 600 * 1000000; // 10*60=600-10 (I want one reading per 10 minutes, taking into account delays etc.)
// ESP32 boot count
RTC_DATA_ATTR int bootCount = 0;
// Enter Deep Sleep with Timer Wake-up source
void deepSleep() {
    esp_sleep_enable_timer_wakeup(SLEEP_DURATION);
    esp_deep_sleep_start();
}



// put your setup code here, to run once:
void setup() {
  Serial.begin(9600);
  
  pinMode(DOOR_SENSOR_PIN, INPUT_PULLUP); // set ESP32 pin to input pull-up mode
  pinMode(trigPin, OUTPUT); // Sets the trigPin as an Output for distance sensor
  pinMode(echoPin, INPUT); // Sets the echoPin as an Input for distance sensor

  // Print boot counter every boot
  ++bootCount;
  Serial.println("Boot number: " + String(bootCount));

  // output OOCSI activity on the built-in LED
  pinMode(LED_BUILTIN, OUTPUT);
  oocsi.setActivityLEDPin(LED_BUILTIN);
  // connect wifi and OOCSI to the server
  oocsi.connect(OOCSIName, hostserver, ssid, password);
}

void loop() {
  // make OOCSI message ready. Insert DF channel here
  oocsi.newMessage("HH_Window_receiver");
  // replace DEVICE with your reference ID from a device
  oocsi.addString("device_id", "dd06e659185134c30");
  // identify participant
  oocsi.addString("participant", "H1");

  // create data messages for OOCSI
    // REED sensor state (open/closed)
  doorState = digitalRead(DOOR_SENSOR_PIN); // read window state (REED SENSOR: 0/1)
  oocsi.addInt("reed sensor", int(doorState)); // the raw analog reading: 0-1
  if (doorState == HIGH) {
    oocsi.addString("window", "open");
  } else {
    oocsi.addString("window", "closed");
  }
    // LDR sensor state (dark, shade, sunlight)
  LDRvalue = analogRead(LIGHT_SENSOR_PIN); //read input from the LDR sensor (between 0 and 4095)
  oocsi.addInt("light sensor", int(LDRvalue)); // the raw analog reading: 0-4095
  if (LDRvalue < 1000) {   // We'll have a few threshholds, qualitatively determined
    oocsi.addString("light", "low");
  } else if (LDRvalue < 2000) {
    oocsi.addString("light", "medium_low");
  } else if (LDRvalue < 300) {
    oocsi.addString("light", "medium_high");
  } else {
    oocsi.addString("light", "high");
  }
    // distance sensor distance value
  // Clears the distance sensor's trigPin
  digitalWrite(trigPin, LOW);
  delayMicroseconds(2);
  // Sets the dinstance sensor's trigPin on HIGH state for 10 micro seconds
  digitalWrite(trigPin, HIGH);
  delayMicroseconds(10);
  digitalWrite(trigPin, LOW);
  // Reads the echoPin, returns the sound wave travel time in microseconds
  duration = pulseIn(echoPin, HIGH);
  // Calculate the distance
  distanceCm = duration * SOUND_SPEED/2;
  // oocsi message
  oocsi.addInt("distance sensor", int(distanceCm));
  if (distanceCm > 30) {
    oocsi.addString("curtain", "open");
  } else {
    oocsi.addString("curtain", "closed");
  }
  oocsi.sendMessage();   // this command will send the message; don't forget to call this after creating a message
  oocsi.printSendMessage();   // prints out the raw message (how it is sent to the OOCSI server)
  oocsi.keepAlive();   // use the check() if you also need to process incoming messages/ use keepAlive() if you do NOT need to receive data from OOCSI

  Serial.println("Entering Deep Sleep mode..."); ////// SLEEP MODE (TO ADJUST SEE SLEEPTIMER ^)
  Serial.flush(); // make sure all data has been sent
  deepSleep();
}
